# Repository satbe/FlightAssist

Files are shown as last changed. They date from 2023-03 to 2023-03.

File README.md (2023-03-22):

# FlightAssist
Device to measure height above water level with an Ultrasonic Sensor.
Print case in ASA-x, seal with epoxy. Glue LED Bar from top, seal with epoxy.
Insert heat inserts. Cut seal from epdm sheet with help of seal_template.
Solder and install eletronics according to schematic drawing.
Arduino Libraries: 
WS2812 LED Bar: https://github.com/FastLED/FastLED
Ultrasonic Sensor: https://github.com/Martinsos/arduino-lib-hc-sr04
Filter: https://github.com/denyssene/SimpleKalmanFilter

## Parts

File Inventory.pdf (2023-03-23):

Link | # | Price | Shipping | Total | Remarks
Ultrasonic sensor IP67 | https://a.aliexpress.com/_mrHMqRY 1 | $9.57 | $4.35 | $13.92 choose the one with trigger, Signal pulse, PWM
Cable Gland M8 stainless | https://a.aliexpress.com/_mNePo9U 1 | $0.95 | $0.94 | $1.89 Brass are OK as well
Arduino Nano v3 clone micro usb | https://a.aliexpress.com/_mKsQGFY1 | $2.41 | $1.37 | $3.78 Atmega 238P micro, 16MHz 5V
Micro-USB male solder connector | https://a.aliexpress.com/_mtwefxy1 | $1.01 | $1.26 | $2.27 20 pcs, 4 pin, you need 1
Pogo 4 pin usb | https://a.aliexpress.com/_mL6JoCK1 | $4.61 | $4.74 | $9.35 Black straight
Lipo Charger/5V Boost converter | https://a.aliexpress.com/_mLzZk1y1 | $2.40 | $1.52 | $3.92 5 pcs, you need 1
Piezzo Button 16mm | https://a.aliexpress.com/_mKvGoHk 1 | $4.36 | $5.64 | $10.00 diameter 16mm; alternative product: https://a.aliexpress.com/_ms2WFO2
Inserts | https://a.aliexpress.com/_m0mI3DC1 | $1.28 | $1.69 | $2.97 M3, OD=4.2mm, L=5mm, 50pcs, you need 18 pcs
LiPO | https://a.aliexpress.com/_m0xH3yI 1 | $4.91 | $2.84 | $7.75
8 x 1 WS2812 RGB Full LED Lamp Panel Module 5V | https://a.aliexpress.com/_mPLBbR81 | $0.47 | $1.20 | $1.67 black
Seal | local craft shop | 1 | $3.00 | $0.00 | $3.00 2mm sheet of EPDM "Moosgummi"
Epoxy
3d printed enclosure
M3 x 10 Stainless Steel Button Head Hex screws | 18
Total | $60.52

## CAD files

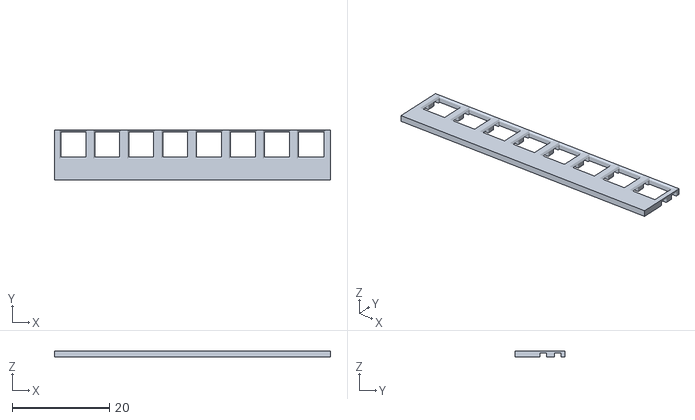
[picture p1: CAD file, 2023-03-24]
LED_Cover.stl
56.9 x 10.3 x 1.20

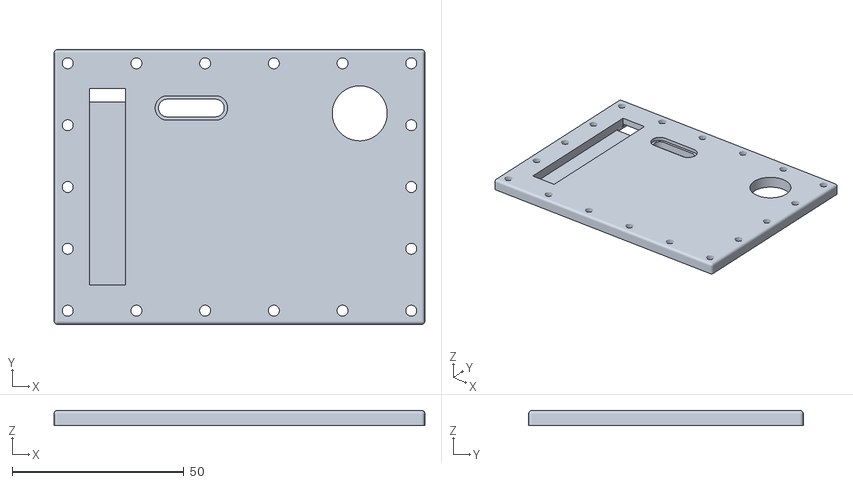
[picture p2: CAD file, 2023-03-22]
Lid.stl
108.0 x 80.0 x 4.40

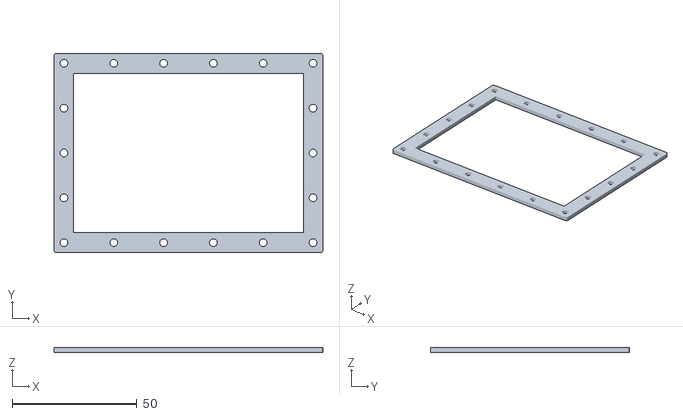
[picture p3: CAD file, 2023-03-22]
Seal_template.stl
108.0 x 80.0 x 2.00

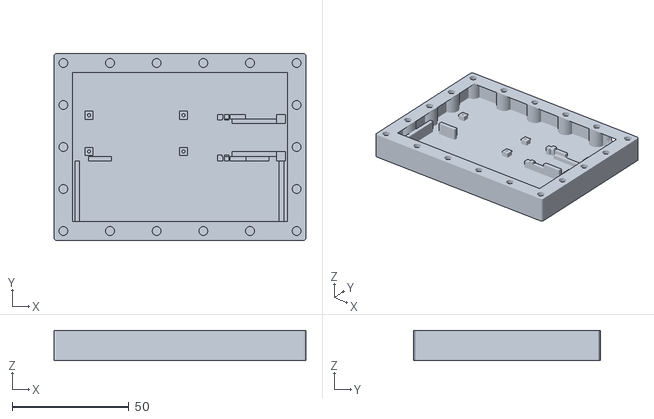
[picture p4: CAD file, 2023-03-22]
Base.stl
108.0 x 80.0 x 13.0

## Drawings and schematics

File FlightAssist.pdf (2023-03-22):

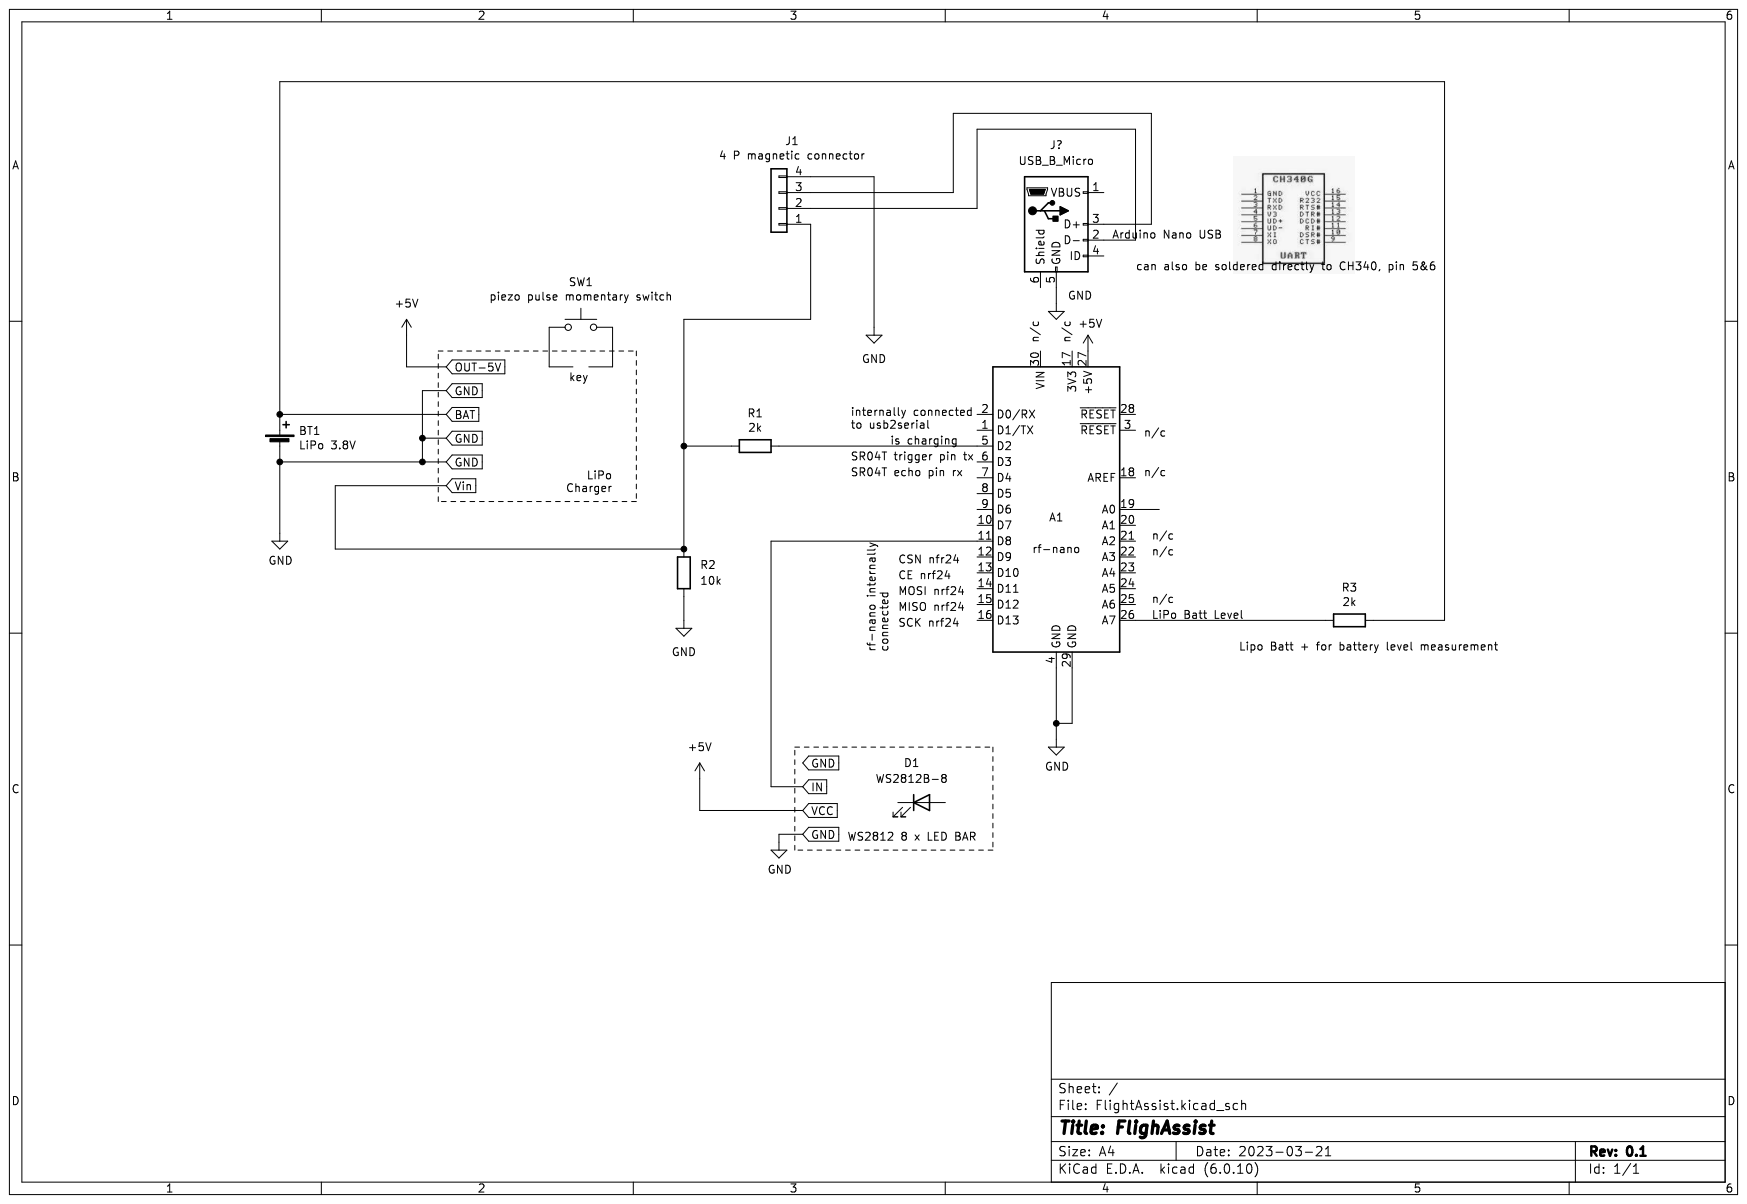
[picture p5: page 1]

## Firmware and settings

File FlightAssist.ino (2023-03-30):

#include <HCSR04.h>
#include "FastLED.h"
#define NUM_LEDS 8
#define LED_PIN 8
#define BRIGHTNESS 255 
#include <dmtimer.h>
#include <math.h>
#include <SimpleKalmanFilter.h>
CRGB leds[NUM_LEDS];


// Initialize sensor that uses digital pins 13 and 12.
const byte triggerPin = 3;
const byte echoPin = 4;
const byte ChargePin = 2;
const byte Lipo_Pin = A7;
int Ubatt = 3.4;  
int BattL = 0;
const byte Hmax = 58;                             // max level in cm above the waterline 
int distanceF;

UltraSonicDistanceSensor distanceSensor(triggerPin, echoPin);
SimpleKalmanFilter FilterUbatt(2, 2, 0.01);       // Filter to get stable receiver battery level
SimpleKalmanFilter FilterHight(20, 20, 0.8);      // Filter to get stable receiver battery level

void setup () {
    pinMode(ChargePin, INPUT);
    pinMode(Lipo_Pin, INPUT); 
    Serial.begin(57600);  // We initialize serial connection so that we could print values from sensor.
    FastLED.addLeds<NEOPIXEL, LED_PIN>(leds, NUM_LEDS);
    FastLED.setBrightness( BRIGHTNESS );
    for(int i=0;i<8;i++){
    Ubatt = FilterUbatt.updateEstimate(map(analogRead(Lipo_Pin), 0, 1023, 0, 510));
    BattL = (Ubatt/10) - 34;                         // 3,4V = 0, 4.2V = 7;  
    for(int i=0;i<8;i++){
    leds[i] = CRGB(4,0,0);                           // Fill  with red, dimmed 
   }
   for(int i=0;i<BattL;i++){
    leds[i] = CRGB(0,4,0);                           // Fill  with green, 3.4-4.2V -> 0-7 green LEDs
   }   
  }
        FastLED.show();
delay(3000);

}

void loop () {  
    int distance = distanceSensor.measureDistanceCm();    
    distanceF = FilterHight.updateEstimate(distance);  
    //Serial.println(round(distance/10));
    
    LedRing(round(distanceF/(Hmax/7)),(Ubatt = FilterUbatt.updateEstimate(map(analogRead(Lipo_Pin), 0, 1023, 0, 510))/10)-34);    // 0-510mV, /10 -> 34 to 42 = 3.4 to 4.2V -> -34 means 0-8 LEDs
    delay(5);                                        // Every 5 miliseconds, do a measurement using the sensor and print the distance in centimeters. 
     Serial.print(distanceF);
     Serial.print(";"); 
}

void LedRing(int dist, int BattLevel) {
  if (dist >= 7) {
    dist = 7;                                        // LED 7 ist the last one
  }
  if (dist>-1) {                                     // only show something if the measurement is valid
  for(int i=0;i<8;i++){
    leds[i] = CRGB(0,0,64);                          // Fill  with blue, dimmed to 25% (256/4=64)
   }
    leds[dist] = CRGB::Green ;
    if (dist == 0) {
    leds[dist] = CRGB(255,0,0);                     // Red
    } 
    if (dist == 1) {
    leds[dist] = CRGB(255,128,0);                   // Orange
    }       
    if (dist == 6) {
    leds[dist] = CRGB(255,128,0);                   // Orange
    }
     if (dist == 7) {
    leds[dist] = CRGB::DarkRed ;                    // Red
    }
//--- Show Charge Level when connected to 5V (charging)
 if (digitalRead(ChargePin) == 1 ) {                // when Charging, show battery level (shows charging voltage -> all green
 for(int i=0;i<8;i++){
    leds[i] = CRGB(4,0,0);                          // Fill  with red, dimmed 
   }
 if (BattLevel >=8  ){
  BattLevel = 8;
 }
 for(int i=0;i<BattLevel;i++){
    leds[i] = CRGB(0,4,0);                         // Fill  with green, 3.4-4.2V -> 0-7 green LEDs
   }   
 }
//--
       FastLED.show();                   
   }
}

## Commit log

2023-03-22 Schematic drawing
2023-03-22 Parts List
    [Inventory.xlsx]
2023-03-23 changed inventory to open office format
    [Inventory.ods, Inventory.xlsx]
2023-03-23 added inventory csv
    [Inventory.csv]
2023-03-23 rem inventory csv
    [Inventory.csv]
2023-03-24 added LED cover frame
    [LED_Cover.stl]
